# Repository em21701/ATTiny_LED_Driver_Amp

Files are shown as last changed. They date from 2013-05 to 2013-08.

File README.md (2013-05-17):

ATTiny_LED_Driver
=================

LED Driver Board using and ATTiny processor for PWM and effects.

The goal of this project is to use the ATTiny as a Buck Driver for High Brightness LEDs. 
After getting a functional Buck Driver working I will add blink effects.

This driver board has 2 inputs and is intended for use as a turn signal/running light 
combo and brake light/running light combo for a motorcycle. As such the board has 2 inputs,
one for 12v power from the key and a second for 12v power from either the turn signal or 
brake light. The Key inuput will illuminate the LEDs to a low level and the second input 
will change the brightness to a significantly higher level.Blink effects will be added when 
used as a tail/brake combo to make the light more conspicuous. 

Currently planned blink effects are an invverted heartbeat and flash and fade. In the heart 
beat pattern the light will dim in a lub-dub pattern while brake light is illuminated. 
In the flash and fade pattern, the brake light will flash to full brightness then slowly fade
to a level brighter than running light level, but noticeably lower than full brightness. The
light will then flash back to full brightness and repeat.

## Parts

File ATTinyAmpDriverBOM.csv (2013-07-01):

Qty | Value | Device | Package | Parts | Description | DESCRIPTION | DIGIKEY | DIGIKEY_COST | MF | MPN | OC_FARNELL | OC_NEWARK | PACKAGE | SUPPLIER
1 | .1 | R-US_R1206 | R1206 | R5 | RESISTOR, American symbol |  | A103268CT-ND | .13
4 | .1u | C-USC0603 | C0603 | C2, C4, C5, C6 | CAPACITOR, American symbol |  | 445-1316-1-ND | .10
1 | 10k | R-US_R0603 | R0603 | R1 | RESISTOR, American symbol |  | RMCF0603FT10K0CT-ND | .04
1 | 10n | C-USC0603 | C0603 | C1 | CAPACITOR, American symbol |  | 445-1311-1-ND | .10
1 | 10u | C-USC0805 | C0805 | C3 | CAPACITOR, American symbol |  | 445-7534-1-ND | .10
3 | 1k | R-US_R0603 | R0603 | R2, R7, R8 | RESISTOR, American symbol |  | RMCF0603FT1K00CT-ND | .04
1 | 28.7K | R-US_R0603 | R0603 | R9 | RESISTOR, American symbol |  | RMCF0603FT28R7CT-ND | .04
1 | 3.3k | R-US_R0603 | R0603 | R6 | RESISTOR, American symbol |  | RMCF0603FT3K30CT-ND | .04
2 | 3.9k | R-US_R0603 | R0603 | R3, R4 | RESISTOR, American symbol |  | RMCF0603FT10K0CT-ND | .04
1 | ATTINY5-TSHR | ATTINY5-TSHR | SOT95P280X145-6N | U2 | Microcontroller | Microcontroller | ATTINY10-TSHRCT-ND | .69 |  | ATTINY5-TSHR | 1841626 | 12T1342 | SOT563-6 | ATMEL
1 | BC846 | BC846 | SOT23 | Q2 | NPN TRANSISTOR |  | BC846BMTFCT-ND | .17
1 | DIODES | MPT2 | 2POL254 | X1 | PHOENIX CONNECTOR |  |  |  |  |  | unknown | unknown
1 | DIODE_0603 | DIODE_0603 | D0603 | D1 |  |  | 641-1002-1-ND | .23
1 | INPUT | MPT3 | 3POL254 | X2 | PHOENIX CONNECTOR |  |  |  |  |  | unknown | unknown
1 | MCP6L2-X_SN | MCP6L2-X_SN | SOIC8-N_MC | U3 |  |  | MCP6L2T-E/SNCT-ND | .64
1 | SI2301CDS | SI2301CDS | SOT-23_POWER | Q1 |  |  | 568-6956-1-ND | .69
1 | SPX5205M5-L-3-3 | SPX5205M5-L-3-3 | SOT95P280X145-5N | U1 | 150mA, LOW-NOISE LDO VOLTAGE REGULATOR |  | 1016-1251-ND | .60 |  | SPX5205M5-L-3-3 | 1831954 | 23R9851 | SOT-23-5 | EXAR
5 | TPI | TPI | TPI_PAD | +5V, GND, RESET, TPICLK, TPIDATA

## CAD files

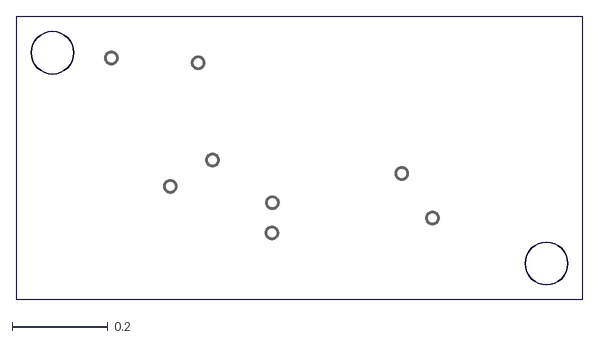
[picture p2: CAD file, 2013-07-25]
ATTinyAmpDriver.dxf
1.18 x 0.592

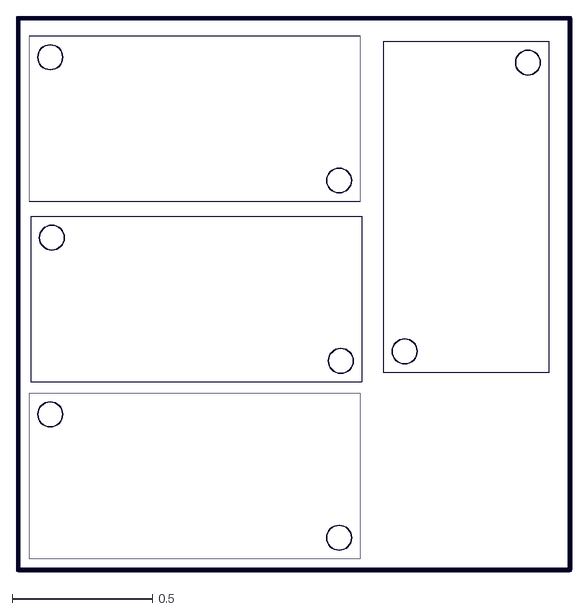
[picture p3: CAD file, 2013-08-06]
Panel/ATTinyAmpDriver_Panel.dxf
1.98 x 1.98

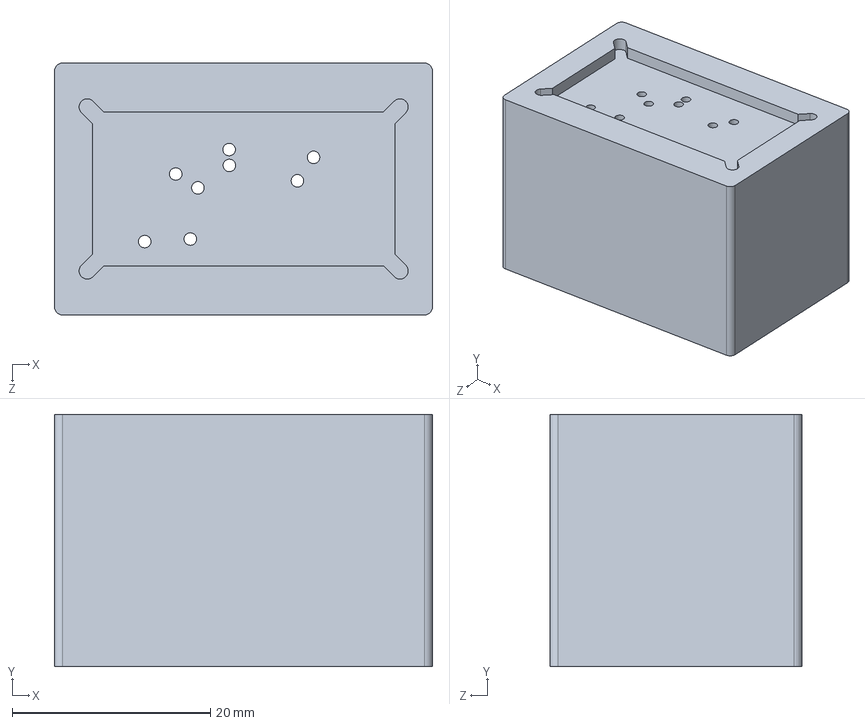
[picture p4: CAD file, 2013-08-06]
Programmer/Fixture_Base.SLDPRT
38.1 x 25.4 x 25.4 mm

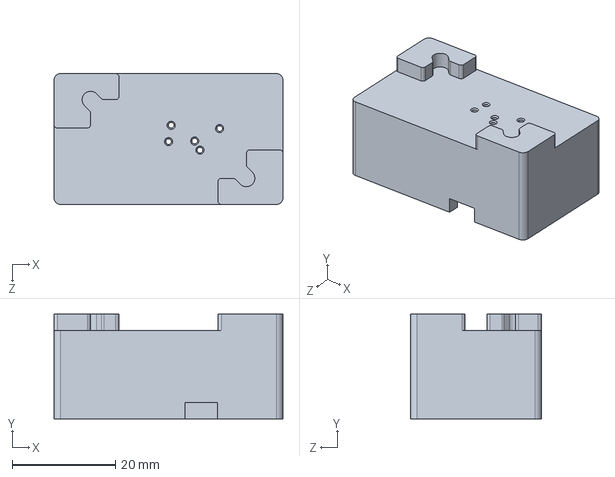
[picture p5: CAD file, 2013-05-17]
Fixture_Base.SLDPRT
44.5 x 20.3 x 25.4 mm

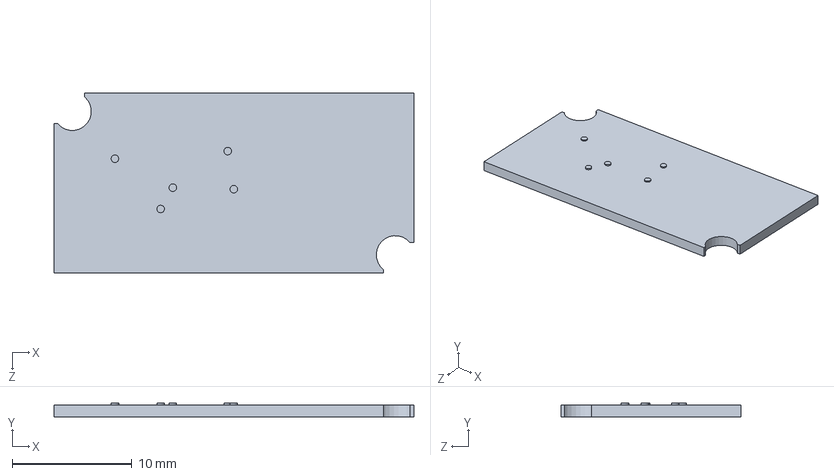
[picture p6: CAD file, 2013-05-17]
Programmer/Board.SLDPRT
30.0 x 1.13 x 15.0 mm

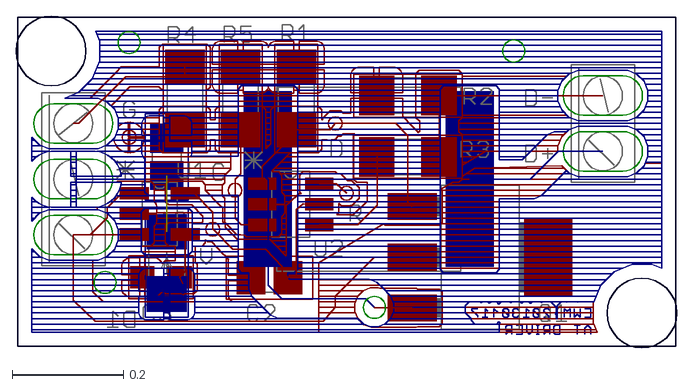
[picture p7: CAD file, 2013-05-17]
ATTiny5.dxf
1.19 x 0.595

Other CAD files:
Fixture_Base.DXF
Fixture_Base.SLDDRW
Programmer/Fixture_Base.SLDDRW

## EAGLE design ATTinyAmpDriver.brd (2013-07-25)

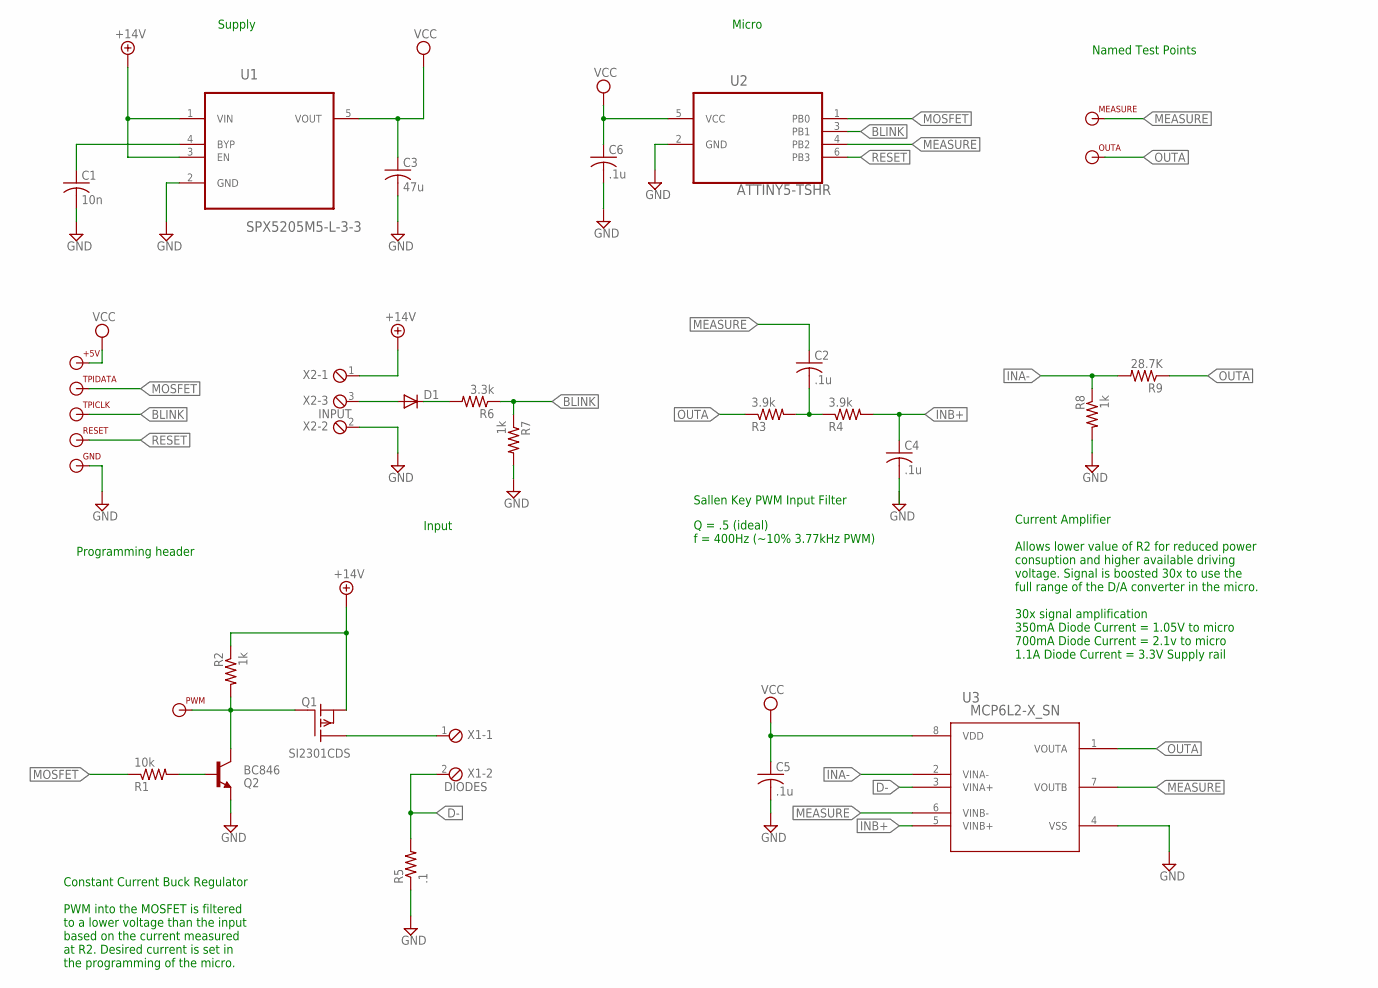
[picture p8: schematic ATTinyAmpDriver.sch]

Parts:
+5V: TPI; TPI_PAD
C1: 10n; C0603; DIGIKEY 445-1311-1-ND
C2, C4, C5, C6: .1u; C0603; DIGIKEY 445-1316-1-ND
C3: 47u; C1206; DIGIKEY 399-5508-1-ND
D1: DIODE_0603; D0603; DIGIKEY 641-1002-1-ND
GND: TPI; TPI_PAD
MEASURE: TPI; TPI_PAD
OUTA: TPI; TPI_PAD
PWM: TPI; TPI_PAD
Q1: SI2301CDS; SOT-23_POWER; DIGIKEY 568-6956-1-ND
Q2: BC846; SOT23; DIGIKEY BC846BMTFCT-ND
R1: 10k; R0603; DIGIKEY RMCF0603FT10K0CT-ND
R2, R7, R8: 1k; R0603; DIGIKEY RMCF0603FT1K00CT-ND
R3, R4: 3.9k; R0603; DIGIKEY RMCF0603FT3K90CT-ND
R5: .1; R1206; DIGIKEY A103268CT-ND
R6: 3.3k; R0603; DIGIKEY RMCF0603FT3K30CT-ND
R9: 28.7K; R0603; DIGIKEY RMCF0603FT28R7CT-ND
RESET: TPI; TPI_PAD
TPICLK: TPI; TPI_PAD
TPIDATA: TPI; TPI_PAD
U1: SPX5205M5-L-3-3; SOT95P280X145-5N; DIGIKEY 1016-1251-ND
U2: ATTINY5-TSHR; SOT95P280X145-6N; DIGIKEY ATTINY10-TSHRCT-ND
U3: MCP6L2-X_SN; SOIC8-N_MC; DIGIKEY MCP6L2T-E/SNCT-ND
X1: DIODES; 2POL254
X2: INPUT; 3POL254

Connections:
+14V: Q1.P$2 (S), R2.1, U1.1 (VIN), U1.3 (EN), X2.1
BLINK: R6.1, R7.1, TPICLK.P$1, U2.3 (PB1)
D-: R5.2, U3.3 (VINA+), X1.2
GND: C1.2, C3.2, C4.2, C5.2, C6.2, GND.P$1, Q2.2 (E), R5.1, R7.2, R8.2, U1.2 (GND), U2.2 (GND), U3.4 (VSS), X2.2
INA-: R8.1, R9.2, U3.2 (VINA-)
INB+: C4.1, R4.2, U3.5 (VINB+)
MEASURE: C2.1, MEASURE.P$1, U2.4 (PB2), U3.6 (VINB-), U3.7 (VOUTB)
MOSFET: R1.1, TPIDATA.P$1, U2.1 (PB0)
unnamed: D1.1A (A), X2.3
unnamed: C1.1, U1.4 (BYP)
unnamed: Q1.P$3 (D), X1.1
unnamed: D1.2C (C), R6.2
unnamed: PWM.P$1, Q1.P$1 (G), Q2.3 (C), R2.2
unnamed: Q2.1 (B), R1.2
unnamed: C2.2, R3.2, R4.1
OUTA: OUTA.P$1, R3.1, R9.1, U3.1 (VOUTA)
RESET: RESET.P$1, U2.6 (PB3)
VCC: +5V.P$1, C3.1, C5.1, C6.1, U1.5 (VOUT), U2.5 (VCC), U3.8 (VDD)

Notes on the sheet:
Supply
Micro
Input
Programming header
Current Amplifier Allows lower value of R2 for reduced power consuption and higher available driving voltage. Signal is boosted 30x to use the full range of the D/A converter in the micro. 30x signal amplification 350mA Diode Current = 1.05V to micro 700mA Diode Current = 2.1v to micro 1.1A Diode C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
Constant Current Buck Regulator PWM into the MOSFET is filtered to a lower voltage than the input based on the current measured at R2. Desired current is set in the programming of the micro.
Sallen Key PWM Input Filter
Q = .5 (ideal) f = 400Hz (~10% 3.77kHz PWM)
Named Test Points

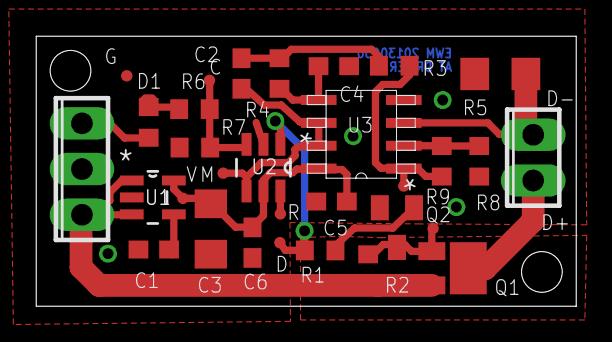
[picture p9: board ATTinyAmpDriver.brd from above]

Board: 2 copper layers, 30.0 x 15.0 mm, 31 parts (0 on the bottom side), 18 nets.

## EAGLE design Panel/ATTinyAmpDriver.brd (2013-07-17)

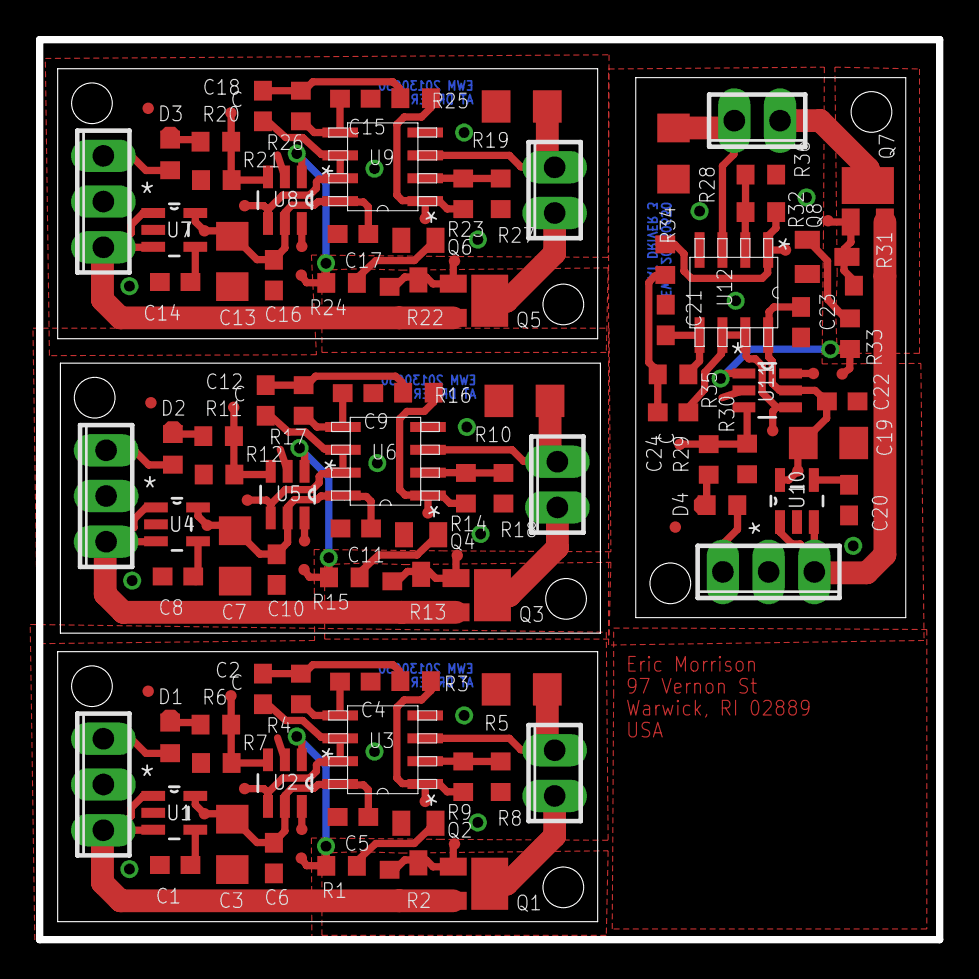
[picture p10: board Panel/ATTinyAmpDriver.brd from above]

Board: 2 copper layers, 50.0 x 50.0 mm, 125 parts (0 on the bottom side), 72 nets.

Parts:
+5V, +5V1, +5V2, +5V3: TPI; TPI_PAD
C1, C8, C14, C20: 10n; C0603
C2, C4, C5, C6, C9, C10, C11, C12, C15, C16, C17, C18, C21, C22, C23, C24: .1u; C0603
C3, C7, C13, C19: 47u; C1206
D1, D2, D3, D4: DIODE_0603; D0603
DRILEGEND: DRILEGEND
GND, GND1, GND2, GND3: TPI; TPI_PAD
MEASURE, MEASURE1, MEASURE2, MEASURE3: TPI; TPI_PAD
OUTA, OUTA1, OUTA2, OUTA3: TPI; TPI_PAD
PWM, PWM1, PWM2, PWM3: TPI; TPI_PAD
Q1, Q3, Q5, Q7: SI2301CDS; SOT-23_POWER
Q2, Q4, Q6, Q8: BC846; SOT23
R1, R15, R24, R33: 10k; R0603
R2, R7, R8, R12, R13, R18, R21, R22, R27, R30, R31, R36: 1k; R0603
R3, R4, R16, R17, R25, R26, R34, R35: 3.9k; R0603
R5, R10, R19, R28: .1; R1206
R6, R11, R20, R29: 3.3k; R0603
R9, R14, R23, R32: 28.7K; R0603
RESET, RESET1, RESET2, RESET3: TPI; TPI_PAD
TPICLK, TPICLK1, TPICLK2, TPICLK3: TPI; TPI_PAD
TPIDATA, TPIDATA1, TPIDATA2, TPIDATA3: TPI; TPI_PAD
U1, U4, U7, U10: SPX5205M5-L-3-3; SOT95P280X145-5N
U2, U5, U8, U11: ATTINY5-TSHR; SOT95P280X145-6N
U3, U6, U9, U12: MCP6L2-X_SN; SOIC8-N_MC
X1, X4, X6, X8: DIODES; 2POL254
X2, X3, X5, X7: INPUT; 3POL254

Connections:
+14V: Q1.P$2, R2.1, U1.1, U1.3, X2.1
+14V1: Q3.P$2, R13.1, U4.1, U4.3, X3.1
+14V2: Q5.P$2, R22.1, U7.1, U7.3, X5.1
+14V3: Q7.P$2, R31.1, U10.1, U10.3, X7.1
BLINK: R6.1, R7.1, TPICLK.P$1, U2.3
BLINK1: R11.1, R12.1, TPICLK1.P$1, U5.3
BLINK2: R20.1, R21.1, TPICLK2.P$1, U8.3
BLINK3: R29.1, R30.1, TPICLK3.P$1, U11.3
D-: R5.2, U3.3, X1.2
D-1: R10.2, U6.3, X4.2
D-2: R19.2, U9.3, X6.2
D-3: R28.2, U12.3, X8.2
GND: C1.2, C3.2, C4.2, C5.2, C6.2, GND.P$1, Q2.2, R5.1, R7.2, R8.2, U1.2, U2.2, U3.4, X2.2
GND1: C7.2, C8.2, C9.2, C10.2, C11.2, GND1.P$1, Q4.2, R10.1, R12.2, R18.2, U4.2, U5.2, U6.4, X3.2
GND2: C13.2, C14.2, C15.2, C16.2, C17.2, GND2.P$1, Q6.2, R19.1, R21.2, R27.2, U7.2, U8.2, U9.4, X5.2
GND3: C19.2, C20.2, C21.2, C22.2, C23.2, GND3.P$1, Q8.2, R28.1, R30.2, R36.2, U10.2, U11.2, U12.4, X7.2
INA-: R8.1, R9.2, U3.2
INA-1: R14.2, R18.1, U6.2
INA-2: R23.2, R27.1, U9.2
INA-3: R32.2, R36.1, U12.2
INB+: C4.1, R4.2, U3.5
INB+1: C9.1, R17.2, U6.5
INB+2: C15.1, R26.2, U9.5
INB+3: C21.1, R35.2, U12.5
MEASURE: C2.1, MEASURE.P$1, U2.4, U3.6, U3.7
MEASURE1: C12.1, MEASURE1.P$1, U5.4, U6.6, U6.7
MEASURE2: C18.1, MEASURE2.P$1, U8.4, U9.6, U9.7
MEASURE3: C24.1, MEASURE3.P$1, U11.4, U12.6, U12.7
MOSFET: R1.1, TPIDATA.P$1, U2.1
MOSFET1: R15.1, TPIDATA1.P$1, U5.1
MOSFET2: R24.1, TPIDATA2.P$1, U8.1
MOSFET3: R33.1, TPIDATA3.P$1, U11.1
unnamed: D1.1A, X2.3
unnamed: C1.1, U1.4
unnamed: Q1.P$3, X1.1
unnamed: D1.2C, R6.2
unnamed: PWM.P$1, Q1.P$1, Q2.3, R2.2
unnamed: Q2.1, R1.2
unnamed: Q3.P$3, X4.1
unnamed: C2.2, R3.2, R4.1
unnamed: C8.1, U4.4
unnamed: PWM1.P$1, Q3.P$1, Q4.3, R13.2
unnamed: Q4.1, R15.2
unnamed: C12.2, R16.2, R17.1
unnamed: D2.1A, X3.3
unnamed: D2.2C, R11.2
unnamed: Q5.P$3, X6.1
unnamed: C14.1, U7.4
unnamed: PWM2.P$1, Q5.P$1, Q6.3, R22.2
unnamed: Q6.1, R24.2
unnamed: C18.2, R25.2, R26.1
unnamed: D3.1A, X5.3
unnamed: D3.2C, R20.2
unnamed: Q7.P$3, X8.1
unnamed: C20.1, U10.4
unnamed: PWM3.P$1, Q7.P$1, Q8.3, R31.2
unnamed: Q8.1, R33.2
unnamed: C24.2, R34.2, R35.1
unnamed: D4.1A, X7.3
unnamed: D4.2C, R29.2
OUTA: OUTA.P$1, R3.1, R9.1, U3.1
OUTA1: OUTA1.P$1, R14.1, R16.1, U6.1
OUTA2: OUTA2.P$1, R23.1, R25.1, U9.1
OUTA3: OUTA3.P$1, R32.1, R34.1, U12.1
RESET: RESET.P$1, U2.6
RESET1: RESET1.P$1, U5.6
RESET2: RESET2.P$1, U8.6
RESET3: RESET3.P$1, U11.6
VCC: +5V.P$1, C3.1, C5.1, C6.1, U1.5, U2.5, U3.8
VCC1: +5V1.P$1, C7.1, C10.1, C11.1, U4.5, U5.5, U6.8
VCC2: +5V2.P$1, C13.1, C16.1, C17.1, U7.5, U8.5, U9.8
VCC3: +5V3.P$1, C19.1, C22.1, C23.1, U10.5, U11.5, U12.8

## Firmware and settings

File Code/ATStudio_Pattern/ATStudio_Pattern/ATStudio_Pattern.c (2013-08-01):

/*
 * buck.c
 *
 *  Created on: June 2, 2013
 *      Author: Eric Morrison
 *
 *					 ATTINY 5
 *					    _____
 *      MOSFET ---- <1 |	 | 6  ---- RESET (PROGRAMMING ONLY)
 *         GND ----  2 |     | 5  ---- VCC
 *       BLINK ---- >3 |_____| 4< ---- MEASURE
 */

#define __AVR_ATtiny5__		//chip definition
#define F_CPU 8000000UL		//cpu frequency 8MHz

#include <avr/io.h>			//AVR chip specific defs
#include <avr/interrupt.h>  //interrupt service routines
#include <stdlib.h>			//standard c functions

#define ADC_PANIC_VALUE 225						//bail out something went horribly wrong
#define LOW 30									//ADC Low value
#define HYSTERESIS 10							//Hysteresis range
#define BLINK 125								//Bright value
#define PANIC_COUNT 50							//number of cycles before we should bail out
#define ADC_DIVIDER 3							//number of cycles PWM value is allowed
												//to settle before a reading it taken
#define TICK_DIVIDER 100						//Divide ADC time scale to something
												//that can be seen
#define PATTERN_LENGTH 100						//max number of cycles before pattern is reset

volatile uint8_t ADC_LOW_VALUE;					//define ADC Lower Limit
volatile uint8_t ADC_HIGH_VALUE;				//define ADC Upper Limit

volatile uint8_t PanicFlag=0;					//define panic flag

volatile uint8_t ADC_Div=0;						//Secondary ADC Divider
												//to minimize flicker ADC had to be slower
												//than 30kHz but to maximize efficiency and
												//component sizes PWM should be as fast as possible

volatile uint8_t PatDiv=0;						//Counter for pattern divider
volatile uint8_t Tick=0;						//Quarter Second tick counter

volatile uint8_t lowVal=0;						//actual output value for low light
volatile uint8_t highVal=0;						//actual ouput value for high light


void setup()
{
	CCP = 0xD8;									//enable protected register change
	// CLKPSR = 0000 -> 0
	// CLKPSR = 0001 -> DIV 2
	// CLKPSR = 0010 -> DIV 4
	// CLKPSR = 0011 -> DIV 8 (default)
	CLKPSR = 0x0000;							//CPU prescaler to 0 = 8MHz

	sei();										//turn on interrupts

	//PWM SETUP
/*	CS00 = 1
	CS01 & CS02 = 0								//Internal Clock no prescaler
	WGM02 = 1
	WGM03 = 0							 		//Fast 8 bit PWM B
	ICNC0 = 0									//Turn Off Noise canceling
	ICES0										//Incoming edge select - rising

	TCCR0B - ICNC0 | ICES0 | - | WGM03 | WGM02 | CS02 | CS01 | CS00
*/
	TCCR0B = 0b01001001;

/*
	WGM00 = 1
	WGM01 = 0									//Fast 8 bit PWM A
	COM0B0 = 0
	COM0B1 = 1									//non-inverting mode
	COM0A0 = 0
	COM0A1 = 1									//non-inverting Mode

	TCCR0A = COM0A1 | COM0A0 | COM0B1 | COM0B0 | - | - | WGM01 | WGM00
*/
	TCCR0A = 0b10100001;

	TCCR0C &= ~((1<<FOC0A) | (1<<FOC0B));		//N/A for PWM must be 0

	DDRB = 0b0001;								//pin1 out all others in
	PUEB = 0b0001;								//enable internal pullup
	PORTB = 0;									//set pins to high impedance

	//OCR0B = 0;									//not used, set to 0

	//ADC SETUP
	PRR &= ~(1<<PRADC);							//turn off adc power reduction

	ADMUX &= ~(1<<MUX0);
	ADMUX |= (1<<MUX1);							//Select PB2 as ADC input

	ADCSRB &= ~((1<<ADTS2) |
				 (1<<ADTS1) |
				 (1<<ADTS0));					//ADC Trigger Source Free Running

	DIDR0 |= (1<<ADC2D);						//Disable digital input
/*
	ADEN = 1									//enable ADC

	//8MHZ CPU div 128 (MAX) = 62.5kHz
	//ADPS = 111 -> 128
	//ADPS = 110 -> 64
	//ADPS = 101 -> 32

	ADIE = 1									//Enable ADC Interrupt
	ADATE = 1									//Auto Trigger

	ADCSRA - ADEN | ADSC | ADATE | ADIF | ADIE | ADPS2 | ADPS1 | ADPS0
*/
	ADCSRA = 0b10101111;

	ADCSRA |= (1<<ADSC);						//Start Conversion


}

void SetLow()
{
	ADC_LOW_VALUE = LOW;				//normal lower limit
	ADC_HIGH_VALUE = LOW + HYSTERESIS;  //normal upper limit
	highVal = OCR0A;
	OCR0A = lowVal;
}

void SetHigh()
{
	ADC_LOW_VALUE = BLINK;					//Bright lower limit
	ADC_HIGH_VALUE = BLINK + HYSTERESIS;  	//Bright upper limit
	lowVal = OCR0A;
	OCR0A = highVal;
}

ISR(ADC_vect)
{
	//check the status of the blink input and change the limits
	//if necessary
	//read value of ADCL compare to low, high and panic values
	//and set new PWM value.

	if (ADC_Div > ADC_DIVIDER)					//The circuit needs time to settle
	{											//Skip ADC_DIVIDER cycles before acting

		if (PINB & (1<<PINB1))					//if the blink input is high
		{
			PatDiv++;							//Increment Pattern divider
			if (PatDiv > TICK_DIVIDER)			//if pattern divider is greater tick divider
			{
				Tick++;							//increment tick
				PatDiv=0;						//reset pattern counter
			}
			switch (Tick)						
			{
				case 2:
				case 4:
				case 6:
					SetLow();					//this is a quick 3 flasses at the start of each cycle
					break;
				case PATTERN_LENGTH:			//if we are at the pattern length
					Tick=0;						//reset tick to 0
					break;
				default:						//otherwise
					SetHigh();					//show a bright light
					break;
			}
		}
		else									//blink input is low
		{
			SetLow();
			Tick=0;								//reset tick
			PatDiv=0;							//reset patdiv
		}
		if (ADCL > ADC_PANIC_VALUE)				//if we are way out of range
		{
			OCR0A -= 5;							//drop PWM a bit
			PanicFlag++;						//increment panic counter
		}
		else if (ADCL < ADC_LOW_VALUE)			//if current is below set point
		{
			//if ((ADC_LOW_VALUE - ADCL) > 30) 	//if it is way below
			//{
				//OCR0A += 10;					//ramp up to the value quickly
			//}
			//else								//otherwise
			//{
				OCR0A += 1;						//lets go slowly to avoid overshoot
			//}
			PanicFlag = 0;						//no need to panic
		}
		else if (ADCL > ADC_HIGH_VALUE)			//if current is above set point
		{
			OCR0A -= 1;							//lets go down slowly
												//rapid drops lead to flicker
		}
		else
		{
			//PWM is perfect, don't fix what isn't broken
			PanicFlag = 0;						//any reason to panic is gone
		}
		ADC_Div = 0;							//reset ADC_DIV for the next round
	}
	else										//skip reading this time this is a settle period
	{
		ADC_Div++;								//increment ADC_DIV
	}

}

int main ()
{
	setup();									//Setup chip;

	while(PanicFlag < PANIC_COUNT)				//if PanicFlag is greater than PANIC_COUNT
	{											//fail out and stop processor.

	}
	OCR0A = 0;									//turn off pwm before bailing out
	return 0;
}

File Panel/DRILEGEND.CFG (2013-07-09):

InputUserCfg = 1
SymbolLayer = 144
SymbolSize = 40
SymbolWidth = 4
TextSize = 70.0000
TextRatio = 5
IdxFnt = 0
decMM = 2
decMIL = 0
SortHoles = 1
TolPlated = 0.02
TolNonPlated = 0.03
PlatedStatusNot = NOT
PlatedStatusBoth = BOTH
PlatedStatusYes = YES
VerticalChart = 1
HighCellFactor = 1.10
WideCellFactor = 1.10
CellOutline = 4
TitleOutline = 4
TableOutline = 8
SymbTitle = Sym
ToolTitle = N°
MMTitle = MM
MilTitle = Mils
MicTitle = Mic
QtyTitle = Qty
TypeTitle = Plated
ToleTitle = Tol
SymbRank = 1
ToolRank = 2
MMRank = 4
MilRank = 3
MicRank = 0
QtyRank = 5
TypeRank = 6
ToleRank = 0
OutputDrillRack = 0
DrillRackFile = DRILLRACK.DRL
Unit = 0
OutputUserCfg = 1
UserCfgFile = DRILEGEND.CFG

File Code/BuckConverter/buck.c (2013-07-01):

/*
 * buck.c
 *
 *  Created on: June 2, 2013
 *      Author: Eric Morrison
 *
 *					 ATTINY 5
 *					    _____
 *      MOSFET ---- <1 |	 | 6  ---- RESET (PROGRAMMING ONLY)
 *         GND ----  2 |     | 5  ---- VCC
 *       BLINK ---- >3 |_____| 4< ---- MEASURE
 */

#define __AVR_ATtiny5__		//chip definition
#define F_CPU 1000000UL		//cpu frequency 1MHz

#include <avr/io.h>			//AVR chip specific defs
#include <avr/interrupt.h>  //interrupt service routines
#include <stdlib.h>			//standard c functions

#define ADC_PANIC_VALUE 160						//bail out something went horribly wrong
#define LOW 30									//ADC Low value
#define HYSTERESIS 10							//Hysterysis range
#define BLINK 100								//Bright value

volatile uint8_t ADC_LOW_VALUE;					//define ADC Lower Limit
volatile uint8_t ADC_HIGH_VALUE;				//define ADC Upper Limit

volatile uint8_t PanicFlag;						//define panic flag

void setup()
{

	PanicFlag = 0;								//set panic flag to false
	sei();										//turn on interrupts

	ADC_LOW_VALUE = LOW;						//Initialize low value
	ADC_HIGH_VALUE = LOW + HYSTERESIS;			//Initialize High Value

	//PWM SETUP
/*	TCCR0B |= (1<<CS00);
	TCCR0B &= ~((1<<CS01) | (1<<CS02));			//Internal Clock no prescaler
	TCCR0B |= (1<<WGM02);
	TCCR0B &= ~(1<< WGM03);				 		//Fast 8 bit PWM B
	TCCR0B &= ~(1<<ICNC0);						//Turn Off Noise canceling
	TCCR0B |= (1<<ICES0);						//Incoming edge select - rising
*/
	//TCCR0B - ICNC0 | ICES0 | - | WGM03 | WGM02 | CS02 | CS01 | CS00
	TCCR0B = 0b01001001;						//same as above in 1 operation

/*
	TCCR0A |= (1<<WGM00);
	TCCR0A &= ~(1<<WGM01);						//Fast 8 bit PWM A
	TCCR0A &= ~(1<<COM0B0);
	TCCR0A |= (1<<COM0B1);						//non-inverting mode
	TCCR0A &= ~(1<<COM0A0);
	TCCR0A |= (1<<COM0A1);						//non-inverting Mode
*/
	//TCCR0A = COM0A1 | COM0A0 | COM0B1 | COM0B0 | - | - | WGM01 | WGM00
	TCCR0A = 0b10100001;

	TCCR0C &= ~((1<<FOC0A) | (1<<FOC0B));		//N/A for PWM must be 0

	DDRB = 0b0001;								//pin1 out all others in
	PUEB = 0b0001;								//enable internal pullup
	PORTB = 0;									//set pins to high impedance
	//OCR0A = 10;									//start PWM at a low value
	OCR0B = 0;

	//ADC SETUP
	PRR &= ~(1<<PRADC);							//turn off adc power reduction

	ADMUX &= ~(1<<MUX0);
	ADMUX |= (1<<MUX1);							//Select PB2 as ADC input

	ADCSRB &= ~((1<<ADTS2) |
				 (1<<ADTS1) |
				 (1<<ADTS0));					//ADC Trigger Source Free Running

	DIDR0 |= (1<<ADC2D);						//Disable digital input
/*
	ADCSRA |= (1<<ADEN);						//enable ADC
	ADCSRA &= ~(1<<ADPS1);						//Set prescaler to div 32
	ADCSRA |= ((1<<ADPS2) |						//31.25kHz @ 1MHz CPU
			 (1<<ADPS0));						//trial and error has the least amount
			 	 	 	 	 	 	 	 	 	//of flicker here

	ADCSRA |= (1<<ADIE);						//Enable ADC Interrupt
	ADCSRA |= (1<<ADATE);						//Auto Trigger
*/
//	ADCSRA - ADEN | ADSC | ADATE | ADIF | ADIE | ADPS2 | ADPS1 | ADPS0
	ADCSRA = 0b10101101;						//same as above in one operation

	ADCSRA |= (1<<ADSC);						//Start Conversion

}

ISR(ADC_vect)
{
	//read value of ADCL compare to low, high and panic values
	//and set new PWM value.

	//There is a race condition here but I don't think it will be an
	//issue. ISR must complete and OCR0A must updated and settle before
	//the next conversion starts to get a good reading.


	if (PINB & (1<<PINB1))					//if the blink input is high
	{
		ADC_LOW_VALUE = BLINK;				//bright lower limit
		ADC_HIGH_VALUE = BLINK + HYSTERESIS;//bright upper limit

	}
	else
	{
		ADC_LOW_VALUE = LOW;				//normal lower limit
		ADC_HIGH_VALUE = LOW + HYSTERESIS;  //normal upper limit
	}

	if (ADCL > ADC_PANIC_VALUE)
	{
		OCR0A = 0;					//set PWM to 0
		PanicFlag++;				//force the chip to end processing
	}
	else if (ADCL < ADC_LOW_VALUE)	//if current is below set point
	{
		if ((ADC_LOW_VALUE - ADCL) > 30) //if it is way below
		{
			OCR0A += 10;			//ramp up to the value quickly
		}
		else						//otherwise
		{
			OCR0A += 1;				//lets go slowly to avoid overshoot
		}
	}
	else if (ADCL > ADC_HIGH_VALUE)	//if current is above set point
	{
		OCR0A -= 2;					//lets go down slowly
									//rapid drops led to flicker so down slowly
									//is the best plan

	}
	else
	{
		//life is good do nothing
	}


}

int main ()
{
	setup();									//Setup chip;

	while(PanicFlag < 1)						//if PanicFlag is greater than 0
	{											//fail out and stop processor.

	}

	return 0;
}

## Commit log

2013-05-17 Initial Commit
    Modified the ATTiny Driver Rev2 Board to include a lower value current
    sense resistor and and amplifier to bring sensing range closer to full
    scale ADC range.
    [ATTiny5.dxf, ATTinyAmpDriver.brd, ATTinyAmpDriver.sch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]
2013-05-17 Fixed Broken link between Board and Schematic.
    Fixed Broken link between Board and Schematic. Created BOM
    [ATTinyAmpDriverBOM.csv]
2013-05-20 Added code samples
    [ATTinyAmpDriverBOM.ods]
2013-06-11 P Channel MOSFET
    Changed from Incorrect N-Channel to P-Channel High side switch on the
    Driver Circuit.
    [ATTinyAmpDriver.brd, ATTinyAmpDriver.sch]
2013-06-12 Added Driving transistor for P-FET
    Added driver transistor to P Channel MOSFET and capacitor to op-amp
    output.
    [ATTinyAmpDriver.brd, ATTinyAmpDriver.sch]
2013-06-13 Added buck driver code:
2013-06-13 Removed LED filter circuit
    [ATTinyAmpDriver.brd, ATTinyAmpDriver.sch]
2013-06-13 Hopefully this will get the ADC functioning
2013-06-14 ATStudio Driver ADC function test
2013-06-14 Still working on getting the ADC functioning
2013-06-16 Removed Cap from OpAmp Output
    [ATTinyAmpDriver.brd, ATTinyAmpDriver.sch]
2013-06-20 Low Pass filter before OpAmp
    [ATTinyAmpDriver.brd, ATTinyAmpDriver.sch]
2013-06-21 Blink code moved to ISR for thread safety
2013-06-21 Changed PWM filter to Sallen Key
    [ATTinyAmpDriver.brd, ATTinyAmpDriver.sch]
2013-06-23 Added a diode to Blink input to prevent back feed if transistor shorts
    [ATTinyAmpDriver.brd, ATTinyAmpDriver.sch, ATTinyAmpDriverBOM.csv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]
2013-06-23 Changed blink diode to regular rectifier diode
    [ATTinyAmpDriver.brd, ATTinyAmpDriver.sch]
2013-06-28 Changed Schematic Layout
    [ATTinyAmpDriver.sch]
2013-07-01 Working code and matching board and schematic
    [ATTinyAmpDriver.brd, ATTinyAmpDriver.sch, FilterCalcs.ods]
2013-07-01 Updated BOM
    [ATTinyAmpDriver.brd, ATTinyAmpDriver.sch, ATTinyAmpDriverBOM.csv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]
2013-07-02 Added Newark pricing to some components
    [ATTinyAmpDriver.brd, ATTinyAmpDriver.sch]
2013-07-03 Added test points around op-amp filter
    [ATTinyAmpDriver.brd, ATTinyAmpDriver.sch]
2013-07-09 Changed C3 to 1206 47uF
    [ATTinyAmpDriver.brd, ATTinyAmpDriver.sch]
2013-07-09 Cleaned up buck code, created buck patterns dir
2013-07-16 Panel Change
    [ATTinyAmpDriver.brd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]
2013-07-17 Panel Update
    [ATTinyAmpDriver.brd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]
2013-07-25 Created Programming Fixture
    [ATTinyAmpDriver.brd, ATTinyAmpDriver.dxf, ATTinyAmpDriver.sch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]
2013-08-01 Changed speed of level change
    Added variables to store previously working values when changing between
    light levels. During the change the PWM is set to the last working value
    for that level. This is currently untested.
2013-08-06 Updated masks and fixture
    [ATTinyAmpDriver_Panel.dxf, Fixture_Base.DXF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]
